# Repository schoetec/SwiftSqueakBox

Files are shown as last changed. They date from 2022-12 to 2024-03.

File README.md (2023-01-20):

# SwiftSqueakBox

Een klein toestel (7cmx7cm) om het geluid van Gierzwaluwen te produceren met als doel zwaluwen naar nest-plaatsen te lokken.

**Waarschijnlijk ben je hier geraakt door de gierzwaluwcontactdag.** 

De Gierzwaluwwerkgroep vlaanderen :
https://www.natuurpunt.be/afdelingen/gierzwaluwenwerkgroep-vlaanderen

Email voor opmerkingen,vragen, bestellingen van printplaatjes of afgewerkte SSB's (enkel versie 3): swiftsqueakbox@gmail.com

**Belangrijk : de hier beschreven schakeling is enkel getest met de MP3 module, DFPlayer van DFRobot (https://www.dfrobot.com/product-1121.html). Wees voorzichtig met bv de MP3-TF-16P, deze ziet er gelijkaardig uit, maar is niet hetzelfde !! (En deze worden soms aangeboden onder de naam van DFPlayer !! ).
De software versie V5.1 werkt ook met MP3-TF-16P (myPlayer_attiny85_v5.1). Onderzoek naar een alternatief zonder deze module is gestart. Meer hierover later.**  

**Voor handleiding en ontwerp beschrijving zie de [project Wiki](https://github.com/schoetec/SwiftSqueakBox/wiki).**
 
**Het project is volledig open source/open hardware en de toegankelijkheid maakt dit een mooi STEM project**  

prototype

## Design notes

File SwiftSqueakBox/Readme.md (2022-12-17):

# Structuur beschrijving

1. Arduino_Swift : bevat de software voor ATTiny84 en ATTiny85/45
2. dplayer_swift_v3.1 : Bevat de kicad 6.0 schema en PCB ontwerp files
3. KiCad_Arduino_Nano_DFPlayer_footprints-master : Bevat het ontwerp voor de DFPlayer kicad footprint.

# Bron verwijzingen:

## Arduino libraries voor dfplayer 
### DFPlayer - A Mini MP3 Player For Arduino

> DFPlayer - A Mini MP3 Player For Arduino
> https://www.dfrobot.com/index.php?route=product/product&product_id=1121
>
> This example shows the all the function of library for DFPlayer.
>
> Created 2016-12-07
> By [Angelo qiao](Angelo.qiao@dfrobot.com)
> 
> GNU Lesser General Public License.
> See <http://www.gnu.org/licenses/> for details.
> All above must be included in any redistribution
> 
> Notice and Trouble shooting
> 
> 1.Connection and Diagram can be found here
> https://www.dfrobot.com/wiki/index.php/DFPlayer_Mini_SKU:DFR0299#Connection_Diagram
> 2.This code is tested on Arduino Uno, Leonardo, Mega boards.

## Kicad footprint design. (deze heb je nodig voor de kicad PCB, dus eerst deze footprint opladen in de kicad footprint library)
### KiCad_Arduino_Nano_DFPlayer_footprints
> Footprints for Arduino Nano and DFPlayer MP3 player because I had to make them. 
>
> (I actually use a 32 pin socket to hold the nano to the board. eBay: 32 pin dip IC socket. 2x16.)
>
> There are already components out there for both, but I couldnt find a footprint.
>
> How
> * Add to your library directory.
> * Example: C:\Program Files\KiCad\share\kicad\library
> * Add library to Cvpcb app. Preferences->footprint libraries-> append with wizard

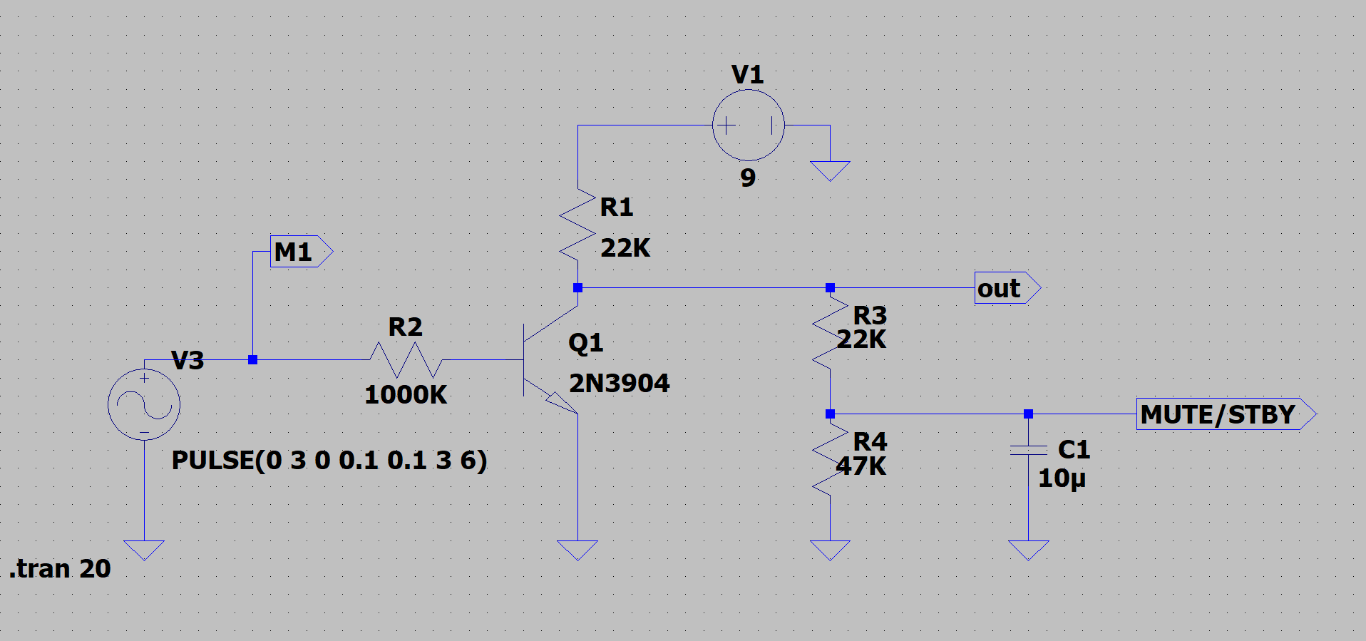
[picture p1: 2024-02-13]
SwiftSqueakBox/amplifier_tda7266/unnamed.png

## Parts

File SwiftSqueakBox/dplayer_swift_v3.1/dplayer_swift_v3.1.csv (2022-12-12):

Source: | C:\Home\src\dplayer_swift_3\dplayer_swift_v3.1\dplayer_swift_v3.1.kicad_sch
Date: | 25/11/2022 13:41:39
Tool: | Eeschema (6.0.5)
Generator: | C:\Program Files\KiCad\6.0\bin\scripting\plugins/bom_csv_grouped_by_value_with_fp.py
Component Count: | 10
Ref | Qnty | Value | Cmp name | Footprint | Description | Vendor
C1, | 1 | 0.1uf | C | Capacitor_THT:C_Rect_L4.6mm_W2.0mm_P2.50mm_MKS02_FKP02 | Unpolarized capacitor
D1, | 1 | LED | LED | LED_THT:LED_D3.0mm | Light emitting diode
LS1, | 1 | Speaker | Speaker | Connector_PinHeader_2.00mm:PinHeader_1x02_P2.00mm_Vertical | Speaker
R1, R2, | 2 | 1K | R | Resistor_THT:R_Axial_DIN0207_L6.3mm_D2.5mm_P7.62mm_Horizontal | Resistor
R3, | 1 | 10K | R | Resistor_THT:R_Axial_DIN0207_L6.3mm_D2.5mm_P7.62mm_Horizontal | Resistor
RV1, | 1 | 10K | R_POT_TRIM-Device | Potentiometer_THT:Potentiometer_Piher_PT-10-V10_Vertical
SW1, | 1 | Reset | SW_Push | Button_Switch_THT:SW_PUSH_6mm_H4.3mm | Push button switch, generic, two pins
U1, | 1 | ATtiny85-20P | ATtiny85-20P | Package_DIP:DIP-8_W7.62mm | 20MHz, 8kB Flash, 512B SRAM, 512B EEPROM, debugWIRE, DIP-8
U2, | 1 | dfplayer | dfplayer-dfplayer | DFPlayer

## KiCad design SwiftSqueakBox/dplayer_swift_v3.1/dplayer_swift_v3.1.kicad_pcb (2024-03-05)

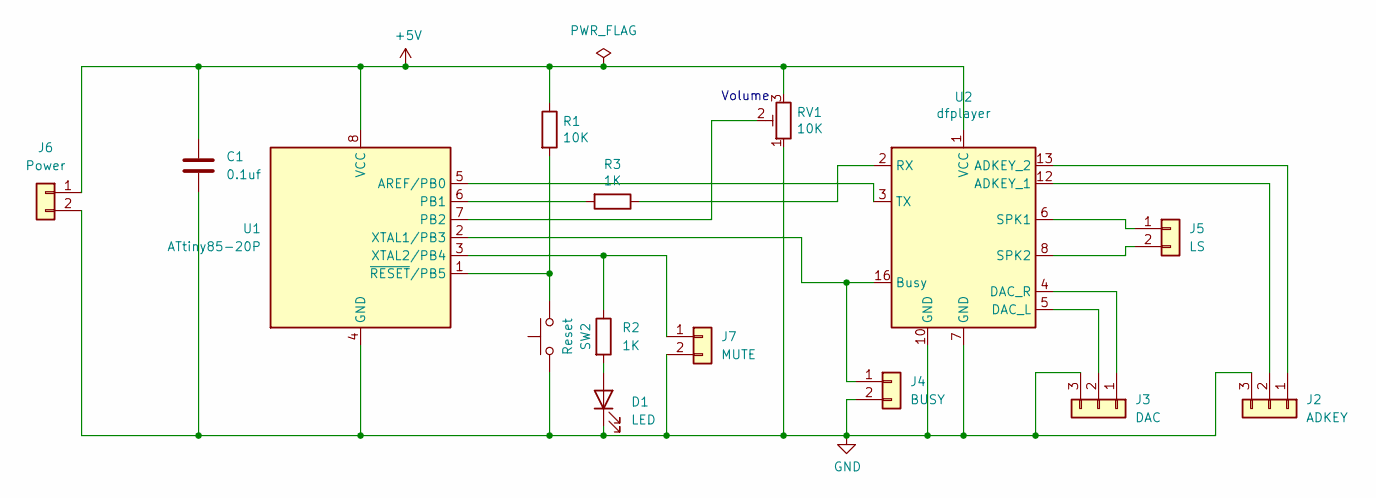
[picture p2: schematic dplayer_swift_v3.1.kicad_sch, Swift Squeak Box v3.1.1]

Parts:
C1: 0.1uf; C_Rect_L4.6mm_W2.0mm_P2.50mm_MKS02_FKP02
D1: LED; LED_D3.0mm
J2: ADKEY; JST_PH_B3B-PH-K_1x03_P2.00mm_Vertical
J3: DAC; JST_PH_B3B-PH-K_1x03_P2.00mm_Vertical
J4: BUSY; JST_PH_B2B-PH-K_1x02_P2.00mm_Vertical
J5: LS; JST_PH_B2B-PH-K_1x02_P2.00mm_Vertical
J6: Power; JST_PH_B2B-PH-K_1x02_P2.00mm_Vertical
J7: MUTE; JST_PH_B2B-PH-K_1x02_P2.00mm_Vertical
R1: 10K; R_Axial_DIN0207_L6.3mm_D2.5mm_P7.62mm_Horizontal
R2, R3: 1K; R_Axial_DIN0207_L6.3mm_D2.5mm_P7.62mm_Horizontal
RV1: 10K; Potentiometer_Piher_PT-10-V10_Vertical
SW2: Reset; SW_PUSH_6mm_H4.3mm
U1: ATtiny85-20P; DIP-8_W7.62mm
U2: dfplayer; DFPlayer

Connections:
+5V: C1.1, J6.1, R1.1, RV1.3, U1.8 (VCC), U2.1 (VCC)
GND: C1.2, D1.1 (K), J2.3, J3.3, J4.2, J6.2, J7.2, RV1.1, SW2.1, U1.4 (GND), U2.7 (GND), U2.10 (GND)
unnamed: D1.2 (A), R2.2
unnamed: J2.1, U2.13 (ADKEY_2)
unnamed: J2.2, U2.12 (ADKEY_1)
unnamed: J3.1, U2.4 (DAC_R)
unnamed: J3.2, U2.5 (DAC_L)
unnamed: J4.1, U1.2 (XTAL1/PB3), U2.16 (Busy)
unnamed: J5.1, U2.6 (SPK1)
unnamed: J5.2, U2.8 (SPK2)
unnamed: R1.2, SW2.2, U1.1 (~RESET/PB5)
unnamed: J7.1, R2.1, U1.3 (XTAL2/PB4)
unnamed: R3.1, U2.2 (RX)
unnamed: R3.2, U1.6 (PB1)
unnamed: RV1.2, U1.7 (PB2)
unnamed: U1.5 (AREF/PB0), U2.3 (TX)

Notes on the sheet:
Volume

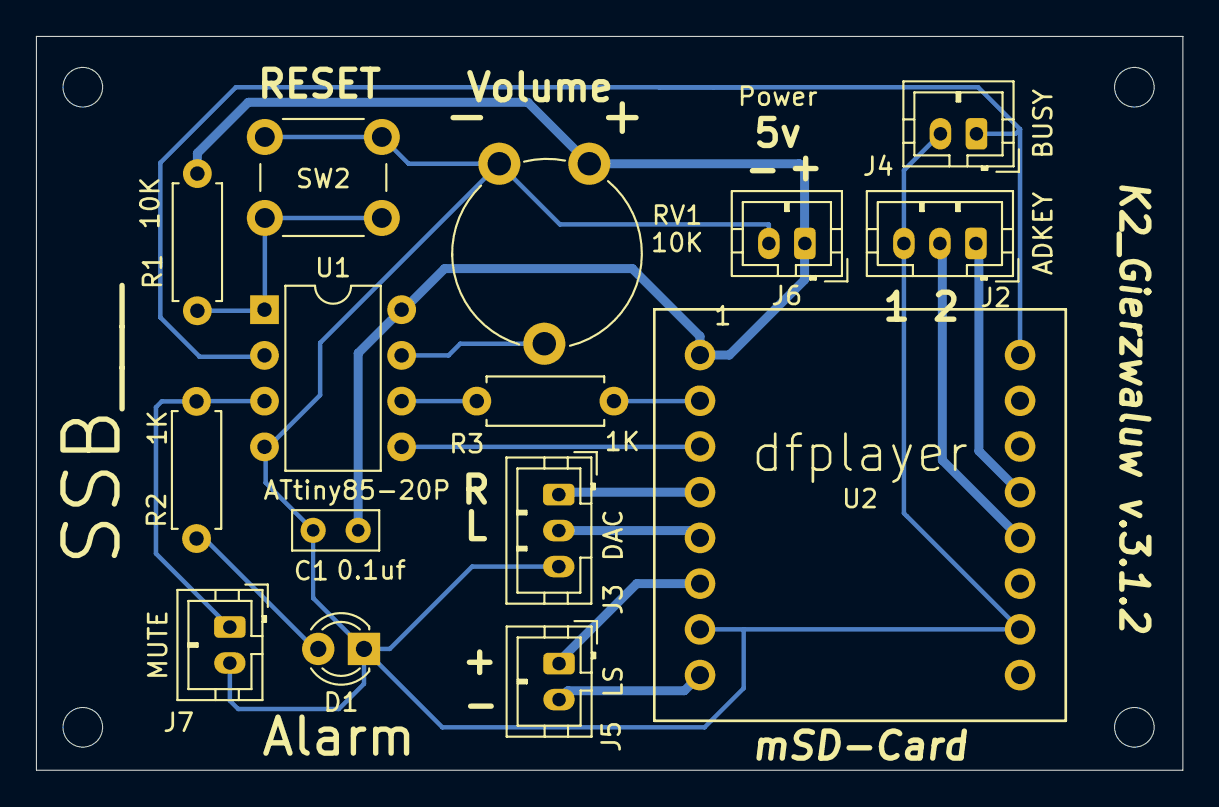
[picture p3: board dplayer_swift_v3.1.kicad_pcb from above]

Board: 2 copper layers, 63.7 x 40.8 mm, 15 parts (0 on the bottom side), 16 nets.

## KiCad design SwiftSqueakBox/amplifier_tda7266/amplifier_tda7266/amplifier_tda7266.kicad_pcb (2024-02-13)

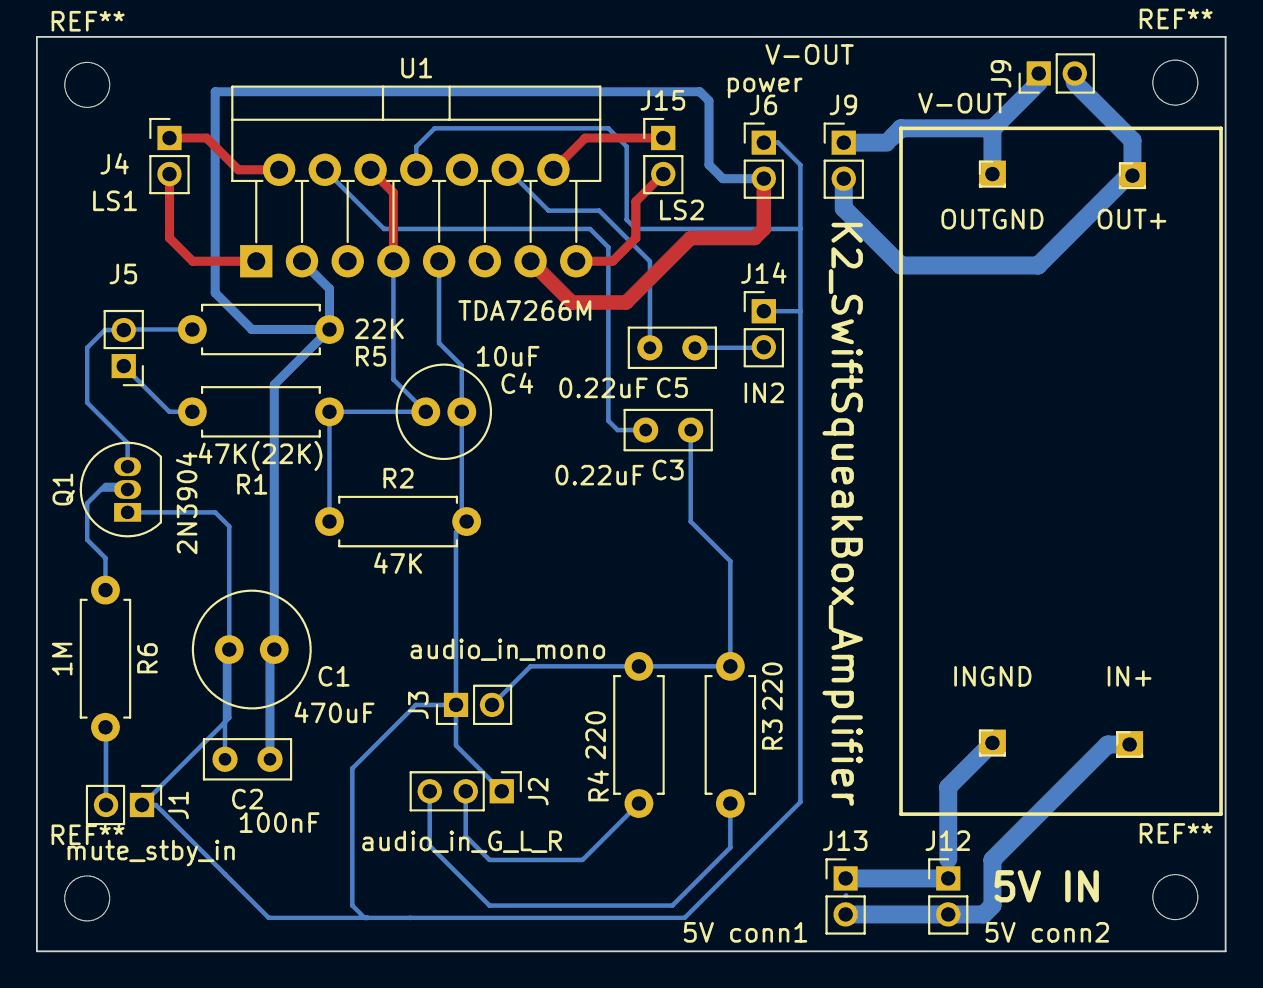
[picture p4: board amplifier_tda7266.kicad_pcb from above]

Board: 2 copper layers, 66.0 x 50.8 mm, 29 parts (0 on the bottom side), 18 nets.

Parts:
C1: 470uF; C_Radial_D6.3mm_H11.0mm_P2.50mm
C2: 100nF; C_Rect_L4.6mm_W2.0mm_P2.50mm_MKS02_FKP02
C3, C5: 0.22uF; C_Rect_L4.6mm_W2.0mm_P2.50mm_MKS02_FKP02
C4: 10uF; C_Radial_D5.0mm_H11.0mm_P2.00mm
IN+: PinHeader_1x01_P1.00mm_Vertical
INGND: PinHeader_1x01_P1.00mm_Vertical
J1: mute_stby_in; PinHeader_1x02_P2.00mm_Vertical
J2: audio_in_G_L_R; PinHeader_1x03_P2.00mm_Vertical
J3: audio_in_mono; PinHeader_1x02_P2.00mm_Vertical
J4: LS1; PinHeader_1x02_P2.00mm_Vertical
J5: Conn_01x02; PinHeader_1x02_P2.00mm_Vertical
J6: power; PinHeader_1x02_P2.00mm_Vertical
J9, J9#2: V-OUT; PinHeader_1x02_P2.00mm_Vertical
J12: 5V conn2; PinHeader_1x02_P2.00mm_Vertical
J13: 5V conn1; PinHeader_1x02_P2.00mm_Vertical
J14: IN2; PinHeader_1x02_P2.00mm_Vertical
J15: LS2; PinHeader_1x02_P2.00mm_Vertical
OUT+: PinHeader_1x01_P1.00mm_Vertical
OUTGND: PinHeader_1x01_P1.00mm_Vertical
Q1: 2N3904; TO-92_Inline
R1: 47K(22K); R_Axial_DIN0207_L6.3mm_D2.5mm_P7.62mm_Horizontal
R2: 47K; R_Axial_DIN0207_L6.3mm_D2.5mm_P7.62mm_Horizontal
R3, R4: 220; R_Axial_DIN0207_L6.3mm_D2.5mm_P7.62mm_Horizontal
R5: 22K; R_Axial_DIN0207_L6.3mm_D2.5mm_P7.62mm_Horizontal
R6: 1M; R_Axial_DIN0207_L6.3mm_D2.5mm_P7.62mm_Horizontal
U1: TDA7266M; TO-220-15_P2.54x2.54mm_StaggerOdd_Lead4.58mm_Vertical

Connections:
GNDPWR: C1.2, C2.2, C4.2, J1.1, J2.1, J3.1, J6.1, J14.1, Q1.1 (E), R2.2, U1.8 (PG), U1.9 (SG)
unnamed: C3.1, J3.2, R3.1, R4.1
unnamed: C3.2, U1.4 (+)
unnamed: C4.1, R1.2, R2.1, U1.6 (MUTE), U1.7 (STBY)
unnamed: J1.2, R6.2
unnamed: J2.2, R4.2
unnamed: J2.3, R3.2
unnamed: J5.1, R1.1
unnamed: J5.2, Q1.3 (C), R5.2
unnamed: J9.2, J9#2.2, OUT+.1
unnamed: J9.1, J9#2.1, OUTGND.1
unnamed: IN+.1, J12.2, J13.2
unnamed: INGND.1, J12.1, J13.1
unnamed: C5.1, J14.2
unnamed: Q1.2 (B), R6.1
unnamed: J4.2, U1.1
unnamed: J4.1, U1.2
VCC: C1.1, C2.1, J6.2, R5.1, U1.3 (V+), U1.13 (V+)

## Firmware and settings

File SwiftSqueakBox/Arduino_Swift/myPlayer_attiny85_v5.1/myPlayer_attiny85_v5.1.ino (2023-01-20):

/***************************************************
DFPlayer - A Mini MP3 Player For Arduino
 <https://www.dfrobot.com/product-1121.html>
 
 ***************************************************
 This example shows the basic function of library for DFPlayer.
 
 Created 2016-12-07
 By [Angelo qiao](Angelo.qiao@dfrobot.com)
 
 GNU Lesser General Public License.
 See <http://www.gnu.org/licenses/> for details.
 All above must be included in any redistribution
 ****************************************************/

/***********Notice and Trouble shooting***************
 1.Connection and Diagram can be found here
 <https://www.dfrobot.com/wiki/index.php/DFPlayer_Mini_SKU:DFR0299#Connection_Diagram>
 2.This code is tested on Arduino Uno, Leonardo, Mega boards.
 ****************************************************/

 /*** Version 2 **/

// Port to attiny85/45 Kris Schoeters

// ATMEL ATTINY84 / ARDUINO
//
//                           +-\/-+
//                     VCC  1|    |14  GND
//             (D 10)  PB0  2|    |13  AREF (D  0)
//             (D  9)  PB1  3|    |12  PA1  (D  1) 
//                     PB3  4|    |11  PA2  (D  2) 
//  PWM  INT0  (D  8)  PB2  5|    |10  PA3  (D  3) 
//  PWM        (D  7)  PA7  6|    |9   PA4  (D  4) 
//  PWM        (D  6)  PA6  7|    |8   PA5  (D  5)        PWM
//                           +----+

// ATMEL ATTINY85/45 / ARDUINO
//
//                           +-\/-+
//   (D 5)(RESET,ADC0) PB5  1|    |8  VCC
//   (D 3)      (ADC3) PB3  2|    |7  PB2 (ADC1)  (D 2)
//   (D 4)      (ADC2) PB4  3|    |6  PB1 (MISO)  (D 1)
//                     GND  4|    |5  PB0 (MOSI)  (D 0)
//                           +----+


#include "Arduino.h"
//#include "SoftwareSerial.h"
#include "DFPlayer.h"
#include <SoftwareSerial.h>

// mp3 RX , TX : 2 , 3
// atu RX , TX : 10, 11
// att RX , TX :  7, 6

// Arduino uno - attiny84
// pin 11 MOSI - 11 TX
// pin 10 PWM  - 10 RX

// Arduino uno - attiny85/45
// pin 11 MOSI - 0 TX
// pin 10 PWM  - 1 RX

#define MP3_RX_PIN              0     //GPIO4/D2 to DFPlayer Mini TX
#define MP3_TX_PIN              1     //GPIO5/D1 to DFPlayer Mini RX
#define MP3_SERIAL_SPEED        9600  //DFPlayer Mini suport only 9600-baud
#define MP3_SERIAL_BUFFER_SIZE  32    //software serial buffer size in bytes, to send 8-bytes you need 11-bytes buffer (start byte+8-data bytes+parity-byte+stop-byte=11-bytes)
#define MP3_SERIAL_TIMEOUT      200   //average DFPlayer response timeout for YX5200, YX5300, JL AAxxxx chip 100msec..200msec

// Arduino uno pin A0=23 - ATtiny A0=0 [13]
int VolumeButton=1; // Volume
// Arduino uno pin 7 - attiny pin 2 [11]
//const int BUTTON_PIN = 2; // the number of the pushbutton pin
// Busy signal input
int BUSY = 3;
// Boot signal output
int BOOT = 4;
//
int delayLoop = 0; //Delays status check
int retryLoop = 0; //Ensure reboot is triggered after number of retry failures exceed.

boolean startFlag=false;

SoftwareSerial mySoftwareSerial =  SoftwareSerial(MP3_RX_PIN,MP3_TX_PIN); // RX, TX
DFPlayer myDFPlayer;

int startPlayerInLoopAll(bool reset) {
  int analogValue = analogRead(VolumeButton);
  // Rescale to potentiometer's voltage (from 0V to 5V):
  int volume = map(analogValue, 0, 1023, 5, 25);
  if(true == reset) {
    for(int i =0 ; i < volume ; i=i+1) {
        digitalWrite(BOOT, HIGH);
        delay(50);
        digitalWrite(BOOT, LOW);
        delay(70);
    }
  }
  myDFPlayer.setEQ(0);
  myDFPlayer.setVolume(volume);  //Set volume value. From 0 to 30
  myDFPlayer.repeatAll(true); 
  myDFPlayer.resume(); 
}

void setup()
{ 
  startFlag=false;
  pinMode(MP3_RX_PIN, INPUT);
  pinMode(MP3_TX_PIN, OUTPUT);
  
  mySoftwareSerial.begin(MP3_SERIAL_SPEED);
 
  pinMode(BUSY,INPUT);
  pinMode(BOOT,OUTPUT);
  digitalWrite(BOOT, LOW);

  //delay startup to prevent DFPlayer lockup 
  for(int i =0 ; i < 10 ; i=i+1) {
        digitalWrite(BOOT, HIGH);
        delay(20);
        digitalWrite(BOOT, LOW);
        delay(50);
  } 
  
  delay(500);
  //
  myDFPlayer.begin(mySoftwareSerial);
  myDFPlayer.stop();                             //if player was runing during ESP8266 reboot
  myDFPlayer.reset();                            //reset all setting to default
  myDFPlayer.setModel(DFPLAYER_MINI);
  myDFPlayer.setEQ(0); 
  myDFPlayer.setSource(2);  //1=USB-Disk, 2=TF-Card, 3=Aux, 4=Sleep, 5=NOR Flash
  startFlag = true; 
}

void loop()
{  
  
  if(startFlag) {
    startFlag=false;
    startPlayerInLoopAll(true);
  }
  
  // Reboot the mp3 player if busy signal is gone unexpected.
  delayLoop = delayLoop + 1;
  if(delayLoop == 1000) {
    int status = digitalRead(BUSY);
    if(status == HIGH) {
      retryLoop = retryLoop + 1;
      if(retryLoop == 2) { //BOOT
        digitalWrite(BOOT, HIGH);
        myDFPlayer.pause();
        delay(200);
        myDFPlayer.reset();
        delay(200);
        startPlayerInLoopAll(false);
        retryLoop=0;    
        delayLoop=0;
      }
    } else {
      retryLoop=0;    
    }
    delayLoop=0; 
  }   
  
  delay(10); 
}

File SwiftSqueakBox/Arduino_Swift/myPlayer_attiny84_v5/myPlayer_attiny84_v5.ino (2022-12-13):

/*
MIT License

Copyright (c) 2022 schoetec

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
THE SOFTWARE IS PROVIDED "AS IS", WITHOUT WARRANTY OF ANY KIND, EXPRESS OR
IMPLIED, INCLUDING BUT NOT LIMITED TO THE WARRANTIES OF MERCHANTABILITY,
FITNESS FOR A PARTICULAR PURPOSE AND NONINFRINGEMENT. IN NO EVENT SHALL THE
AUTHORS OR COPYRIGHT HOLDERS BE LIABLE FOR ANY CLAIM, DAMAGES OR OTHER
LIABILITY, WHETHER IN AN ACTION OF CONTRACT, TORT OR OTHERWISE, ARISING FROM,
OUT OF OR IN CONNECTION WITH THE SOFTWARE OR THE USE OR OTHER DEALINGS IN THE
SOFTWARE.
*/


/***************************************************
 * Swift Squeak Box
 * Code as used for version 2
 * ATTiny84-20PU
 * 
 * Author : Schoeters Kris
 * 
 */

/***************************************************
DFPlayer - A Mini MP3 Player For Arduino
 <https://www.dfrobot.com/product-1121.html>
 
 ***************************************************
 Used library for DFPlayer.
 
 Created 2016-12-07
 By [Angelo qiao](Angelo.qiao@dfrobot.com)
 
 GNU Lesser General Public License.
 See <http://www.gnu.org/licenses/> for details.
 All above must be included in any redistribution
 ****************************************************/

/***********Notice and Trouble shooting***************
 1.Connection and Diagram can be found here
 <https://www.dfrobot.com/wiki/index.php/DFPlayer_Mini_SKU:DFR0299#Connection_Diagram>
 2.This code is tested on Arduino Uno, Leonardo, Mega boards.
 ****************************************************/

 /*** Version 2 **/

// Port to attiny84 Kris Schoeters

// Swift Squeak Box project

// ATMEL ATTINY84 / ARDUINO
//
//                           +-\/-+
//                     VCC  1|    |14  GND
//             (D 10)  PB0  2|    |13  AREF (D  0)
//             (D  9)  PB1  3|    |12  PA1  (D  1) 
//                     PB3  4|    |11  PA2  (D  2) 
//  PWM  INT0  (D  8)  PB2  5|    |10  PA3  (D  3) 
//  PWM        (D  7)  PA7  6|    |9   PA4  (D  4) 
//  PWM        (D  6)  PA6  7|    |8   PA5  (D  5)        PWM
//                           +----+



#include "Arduino.h"
//#include "SoftwareSerial.h"
#include "DFRobotDFPlayerMini.h"
#include <SoftwareSerial.h>

// mp3 RX , TX : 2 , 3
// atu RX , TX : 10, 11
// att RX , TX :  7, 6

// Arduino uno - attiny84
// pin 11 MOSI - 6
// pin 10 PWM  - 7

int RX=7;
int TX=6;
// Arduino uno pin A0=23 - ATtiny A0=0 [13]
int A0_=0; // Volume
// Arduino uno pin 7 - attiny pin 2 [11]
const int BUTTON_PIN = 2; // the number of the pushbutton pin
// Busy signal input
int BUSY = 1;
// Boot signal output
int BOOT = 3;
//
int delayLoop = 0; //Delays status check
int retryLoop = 0; //Ensure reboot is triggered after number of retry failures exceed.
int boot_happened = 0;

SoftwareSerial mySoftwareSerial(RX, TX); // RX, TX
DFRobotDFPlayerMini myDFPlayer;
// constants won't change. They're used here to set pin numbers:
// Variables will change:
int currentState;    // the current reading from the input pin
bool pauseToggle = false;
int lastState = HIGH;
bool _blink = true;

int startPlayerInLoopall() {
   // read the input on analog pin A0:
  int analogValue = analogRead(A0);
  // Rescale to potentiometer's voltage (from 0V to 5V):
  int volume = map(analogValue, 0, 1023, 0, 25);
  myDFPlayer.EQ(DFPLAYER_EQ_NORMAL);
  myDFPlayer.volume(volume);  //Set volume value. From 0 to 30
  myDFPlayer.enableLoopAll();  
}

void setup()
{

 
  delay(1000);

  pinMode(RX,INPUT);
  pinMode(TX,OUTPUT);
  
  mySoftwareSerial.begin(9600);
   
  pinMode(BUTTON_PIN, INPUT_PULLUP);

  pinMode(BUSY,INPUT);
  pinMode(BOOT,OUTPUT);
  
  if (!myDFPlayer.begin(mySoftwareSerial)) {  //Use softwareSerial to communicate with mp3.
    while(true){
      delay(100); // Code to compatible with ESP8266 watch dog.
    }
  }
  //
  startPlayerInLoopall();
}

void loop()
{
  // read the state of the switch/button:
  currentState = digitalRead(BUTTON_PIN);
  if(lastState == LOW && currentState == HIGH) {
    pauseToggle = !pauseToggle;
    if(true == pauseToggle)  {
      if( 0 == boot_happened) {
        digitalWrite(BOOT, HIGH);
        
      }
      myDFPlayer.pause();
    }
    if(false == pauseToggle) {
      if( 0 == boot_happened) {
        digitalWrite(BOOT, LOW);
        _blink = !_blink;
      }
      startPlayerInLoopall();
    }
  }
  // save the last state
  lastState = currentState;  
  // Reboot the mp3 player if busy signal is gone unexpected.
  delayLoop = delayLoop + 1;
  if(delayLoop == 1000) {
    int status = digitalRead(BUSY);
    if( (status == HIGH) && (false == pauseToggle)) {
      digitalWrite(BOOT, HIGH);
      retryLoop = retryLoop + 1;
      if(retryLoop == 5) { //BOOT
        digitalWrite(BOOT, HIGH);
        myDFPlayer.pause();
        delay(1000);
        myDFPlayer.reset();
        delay(1000);
        startPlayerInLoopall();
        retryLoop=0;    
        delayLoop=0;
        boot_happened=1;
      }
    } else {
      if(true == pauseToggle && 0 == boot_happened) {
        if(_blink) {
          digitalWrite(BOOT, HIGH);
        } else {
          digitalWrite(BOOT, LOW);        
        }
        _blink = !_blink;
      }      
      retryLoop=0;    
    }
    delayLoop=0; 
  }   
  
  delay(10); 
}

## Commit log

2023-01-18 Add delay during startup with led indicator
    Ensure that the DFPlayer is started correctly
    [myPlayer_attiny85_v5.ino]
2023-05-26 update pcb and schematic
    [dplayer_swift_v3.1.kicad_pcb, dplayer_swift_v3.1.kicad_sch]
2024-02-13 Add amplifier, minor update to dplayer pcb
    [amplifier_tda7266.kicad_pcb, amplifier_tda7266.kicad_sch, dplayer_swift_v3.1.kicad_pcb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]
2024-03-05 Update SSB Schematic and pcb V3.1.2
    [dplayer_swift_v3.1.kicad_pcb, dplayer_swift_v3.1.kicad_sch]
